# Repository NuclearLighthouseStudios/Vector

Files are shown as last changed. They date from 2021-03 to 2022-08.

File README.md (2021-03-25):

# Vector Hysteresis Distortion

These are the KiCAD schematics and board layout filed for my Vector Hysteresis Distortion pedal.  
If you just want the Gerber files or a PDF of the schematic check out the releases tab for downloads.

This PCB should be easily manufacturable with most online PCB houses by just uploading the gerber files.

This board is designed to be used with my Switchboard Pedal IO PCB which you can find [here](https://github.com/NuclearLighthouseStudios/Switchboard).

## BOM

| Reference | Quantity | Value  | Description |
| :--- | ---: | -----: | :--- |
| C1 C3 C5 C6 C7  | 5 | 100n | WIMA MKS2 63V |
| C2 C8 | 2 | 1µ | WIMA MKS2 50V |
| C4 | 1 | 470n | WIMA MKS2 50V |
| D1 D2 | 2 | 1N4148 | DO-35 Diode |
| J1 | 1 | | Pin Header, 6 pins, 2.54mm spacing |
| J2 | 1 | | DC Barrel Jack with internal switch |
| Q1 Q2 Q3 Q4 | 4 | BC547B | 0.1A Ic, 45V Vce, Small Signal NPN Transistor, TO-92 |
| R1 R2 R5 R13 | 4 | 1M | Metal film resistor 1%, DIN 0207 |
| R3 R14 | 2 | 10k | Metal film resistor 1%, DIN 0207 |
| R4 R7 R8 R9 R12 | 5 | 100k | Metal film resistor 1%, DIN 0207 |
| R6 R10 | 2 | 470k | Metal film resistor 1%, DIN 0207 |
| R11 | 1 | 22k | Metal film resistor 1%, DIN 0207 |
| R15 | 1 | 39k | Metal film resistor 1%, DIN 0207 |
| RV1 RV2 | 2 | 100k | Alps RK09K1130C94 Potentiometer |

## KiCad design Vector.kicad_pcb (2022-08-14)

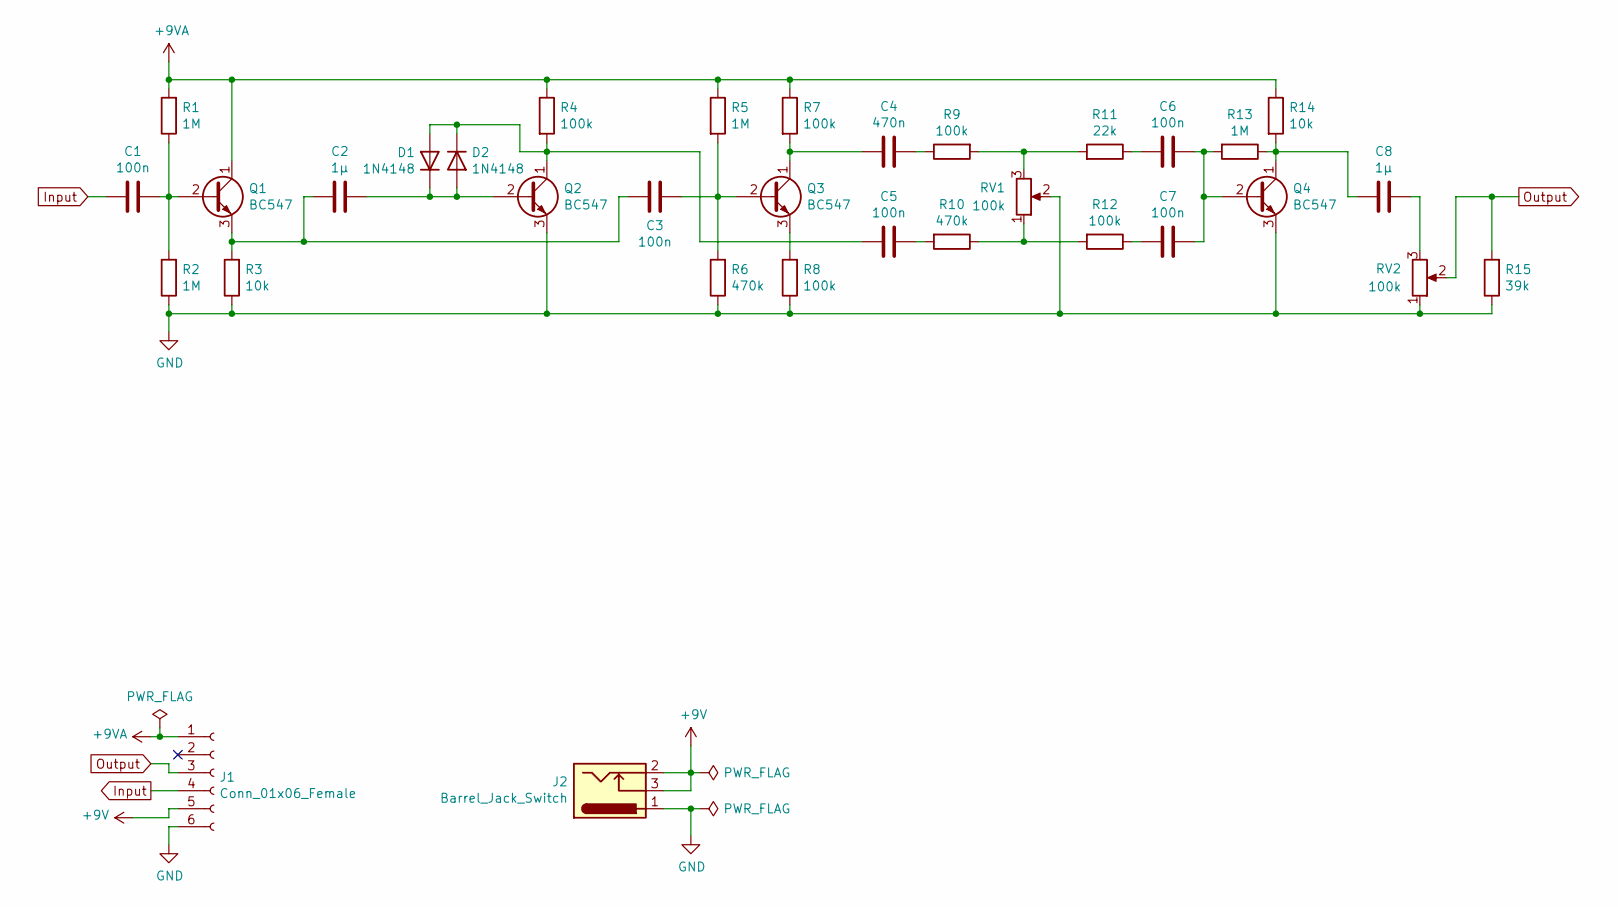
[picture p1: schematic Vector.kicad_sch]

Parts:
C1, C3, C5, C6, C7: 100n; C_Rect_L7.2mm_W2.5mm_P5.00mm_FKS2_FKP2_MKS2_MKP2
C2, C8: 1µ; C_Rect_L7.2mm_W4.5mm_P5.00mm_FKS2_FKP2_MKS2_MKP2
C4: 470n; C_Rect_L7.2mm_W3.5mm_P5.00mm_FKS2_FKP2_MKS2_MKP2
D1, D2: 1N4148; D_DO-35_SOD27_P2.54mm_Vertical_AnodeUp
J1: Conn_01x06_Female; PinHeader_1x06_P2.54mm_Vertical
J2: Barrel_Jack_Switch; BarrelJack_Horizontal_Short
Q1, Q2, Q3, Q4: BC547; TO-92_Wide
R1, R2, R5, R13: 1M; R_Axial_DIN0207_L6.3mm_D2.5mm_P2.54mm_Vertical
R3, R14: 10k; R_Axial_DIN0207_L6.3mm_D2.5mm_P2.54mm_Vertical
R4, R7, R8, R9: 100k; R_Axial_DIN0207_L6.3mm_D2.5mm_P2.54mm_Vertical
R6: 470k; R_Axial_DIN0207_L6.3mm_D2.5mm_P2.54mm_Vertical
R10: 470k; R_Axial_DIN0207_L6.3mm_D2.5mm_P7.62mm_Horizontal
R11: 22k; R_Axial_DIN0207_L6.3mm_D2.5mm_P7.62mm_Horizontal
R12: 100k; R_Axial_DIN0207_L6.3mm_D2.5mm_P7.62mm_Horizontal
R15: 39k; R_Axial_DIN0207_L6.3mm_D2.5mm_P7.62mm_Horizontal
RV1, RV2: 100k; Potentiometer_Alps_RK09K_Single_Vertical

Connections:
+9V: J1.5, J2.2, J2.3
+9VA: J1.1, Q1.1 (C), R1.2, R4.1, R5.1, R7.1, R14.1
GND: J1.6, J2.1, Q2.3 (E), Q4.3 (E), R2.1, R3.1, R6.1, R8.1, R15.1, RV1.2, RV2.1
Input: C1.2, J1.4
unnamed: C1.1, Q1.2 (B), R1.1, R2.2
unnamed: C2.1, C3.2, Q1.3 (E), R3.2
unnamed: C2.2, D1.1 (K), D2.2 (A), Q2.2 (B)
unnamed: C3.1, Q3.2 (B), R5.2, R6.2
unnamed: C4.1, R9.1
unnamed: C4.2, Q3.1 (C), R7.2
unnamed: C5.1, R10.2
unnamed: C5.2, D1.2 (A), D2.1 (K), Q2.1 (C), R4.2
unnamed: C6.1, C7.1, Q4.2 (B), R13.2
unnamed: C6.2, R11.1
unnamed: C7.2, R12.1
unnamed: C8.1, RV2.3
unnamed: C8.2, Q4.1 (C), R13.1, R14.2
unnamed: Q3.3 (E), R8.2
unnamed: R10.1, R12.2, RV1.1
unnamed: R9.2, R11.2, RV1.3
Output: J1.3, R15.2, RV2.2

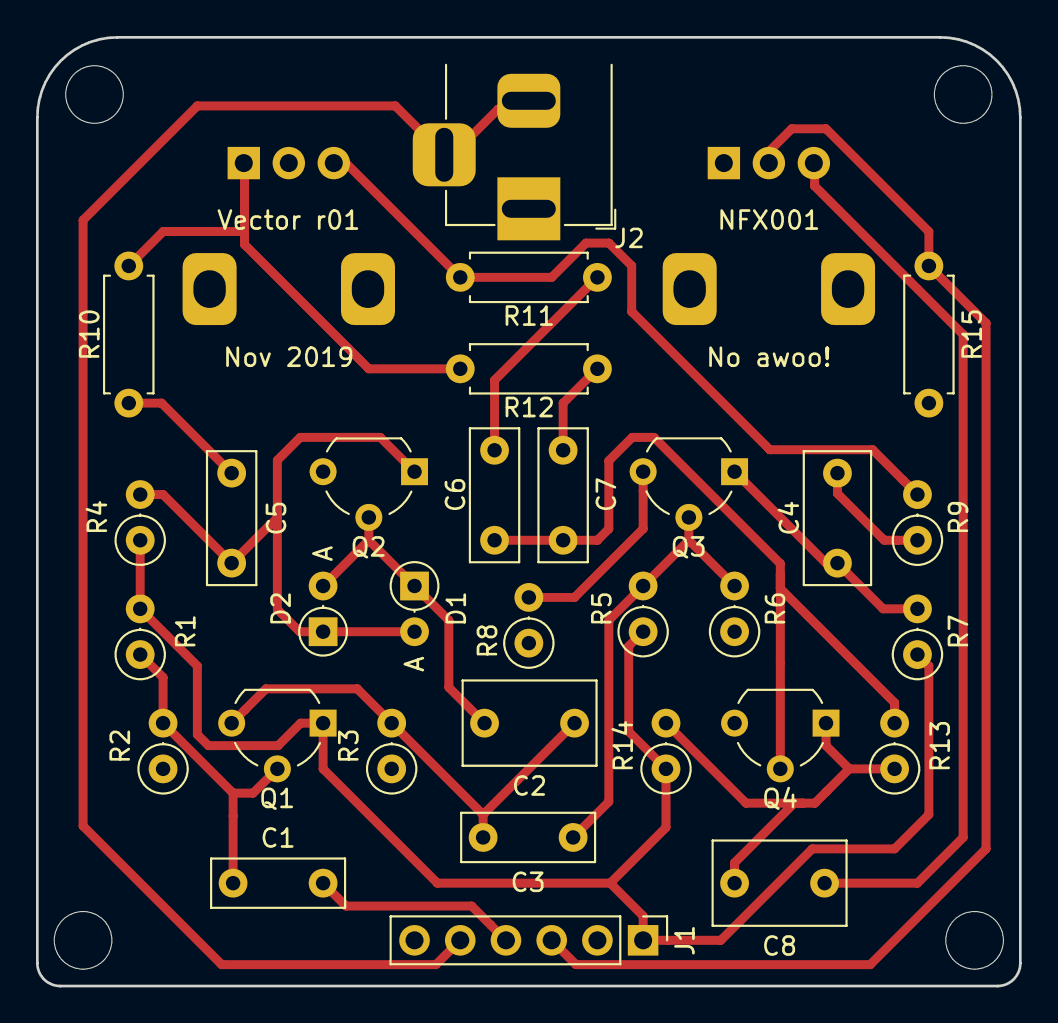
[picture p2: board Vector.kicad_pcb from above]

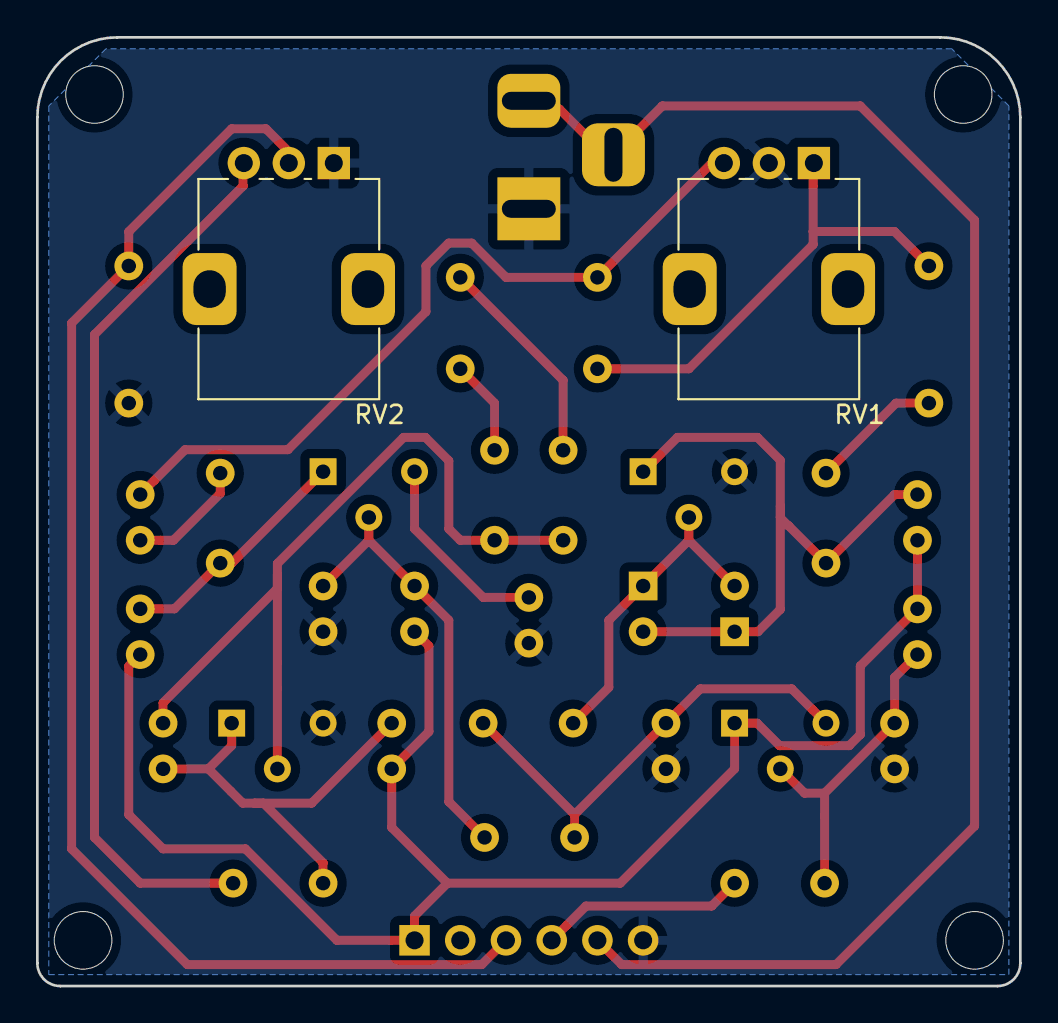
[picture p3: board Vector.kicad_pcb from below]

Board: 2 copper layers, 54.6 x 52.7 mm, 33 parts (2 on the bottom side), 21 nets.

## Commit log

2020-12-30 Open Source, yay!
    [Vector.kicad_pcb, Vector.sch]
2020-12-31 Fix cap voltages
2022-08-14 Migrate to KiCAD 6
    [Vector.kicad_pcb, Vector.kicad_sch, Vector.sch]
2022-08-14 Remove unused footprint libraries
2022-08-14 Update symbols/footprints from libraries
    [Vector.kicad_pcb, Vector.kicad_sch]
2022-08-14 Fix DRC errors
    [Vector.kicad_pcb]

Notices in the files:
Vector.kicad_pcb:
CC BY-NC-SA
